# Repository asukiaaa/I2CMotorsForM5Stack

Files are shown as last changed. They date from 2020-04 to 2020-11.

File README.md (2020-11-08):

# I2cMotorsForM5Stack

A motor driver with using atmega328p for M5Stack.

# TODO

- Replace D3 to small current and high voltage one

# Components

- [TB6612FNG](http://akizukidenshi.com/catalog/g/gI-11317/)
- [Diode](https://akizukidenshi.com/catalog/g/gI-02073/)
- [Terminal block](https://akizukidenshi.com/catalog/g/gP-08370/)
- Gear motor 6v200rpm

# License

MIT

# References

- [SparkFun Motor Driver - Dual TB6612FNG (1A)](https://www.sparkfun.com/products/14451)
- [CavityForM5Stack](https://github.com/asukiaaa/CavityForM5Stack)
- [Arduino Pro Mini schematic (PDF)](https://www.arduino.cc/en/uploads/Main/Arduino-Pro-Mini-schematic.pdf)

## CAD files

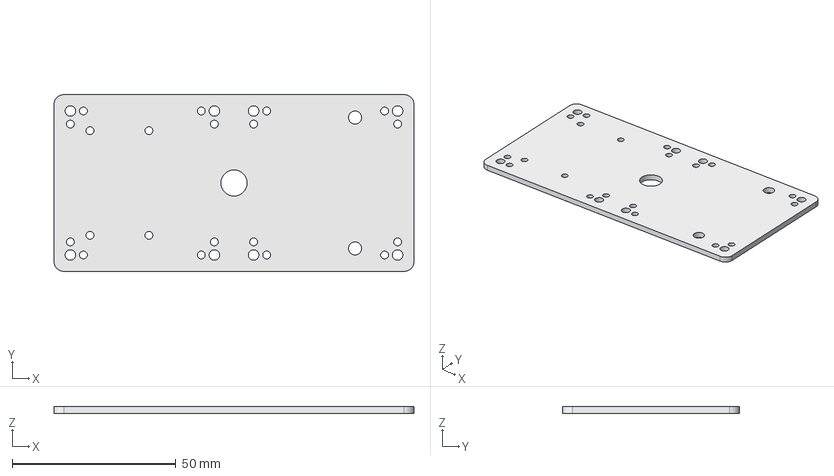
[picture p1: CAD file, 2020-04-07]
plate/plate.FCStd
110.0 x 54.0 x 2.00 mm

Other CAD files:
plate/plate.dxf

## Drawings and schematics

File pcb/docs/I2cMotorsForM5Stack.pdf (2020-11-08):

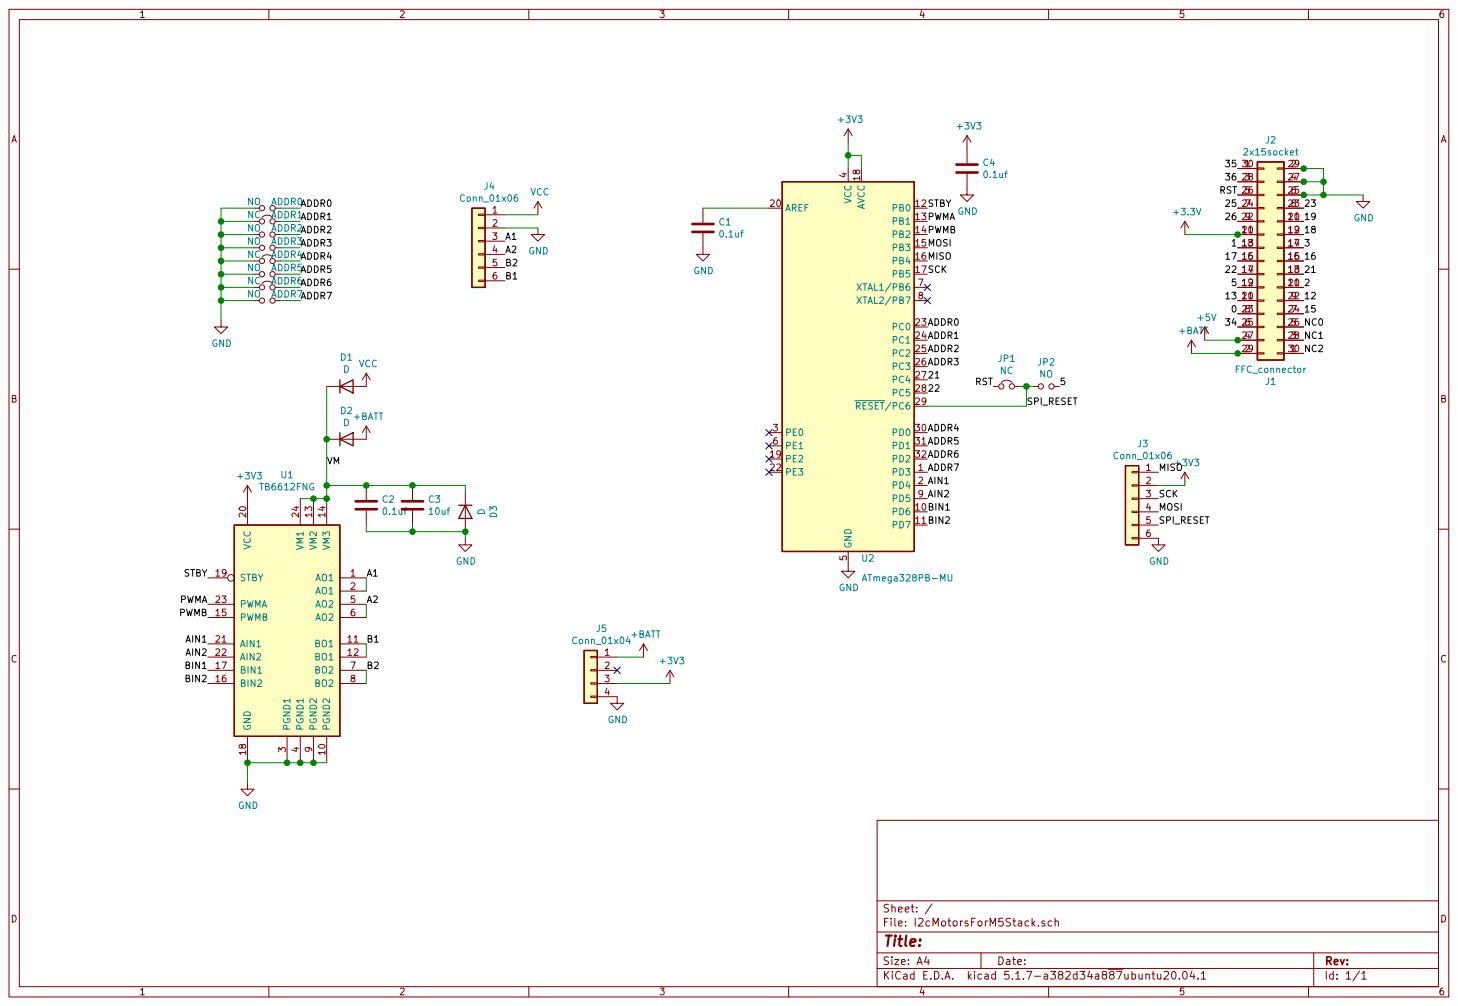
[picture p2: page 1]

Id: 1/1 Title: File: I2cMotorsForM5Stack.sch Sheet: /

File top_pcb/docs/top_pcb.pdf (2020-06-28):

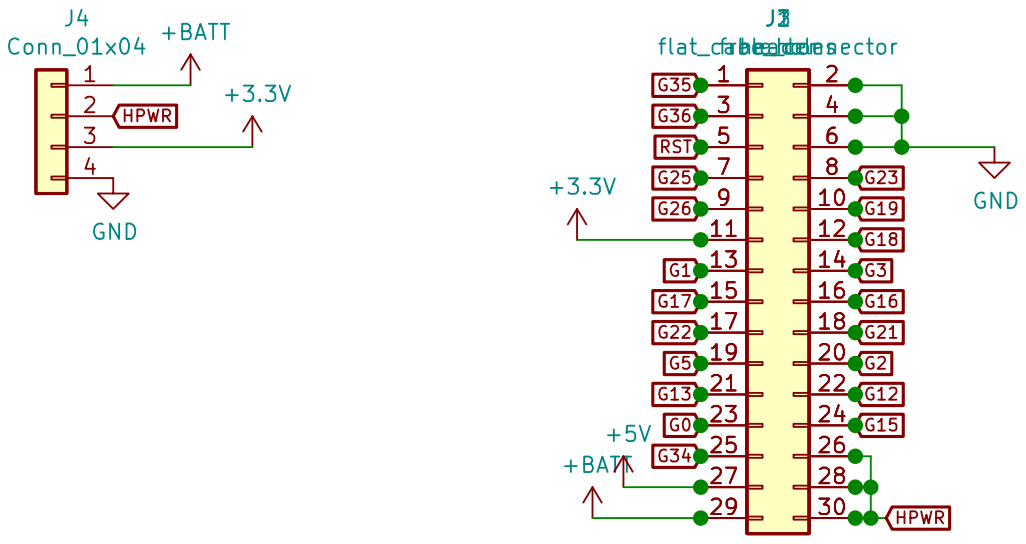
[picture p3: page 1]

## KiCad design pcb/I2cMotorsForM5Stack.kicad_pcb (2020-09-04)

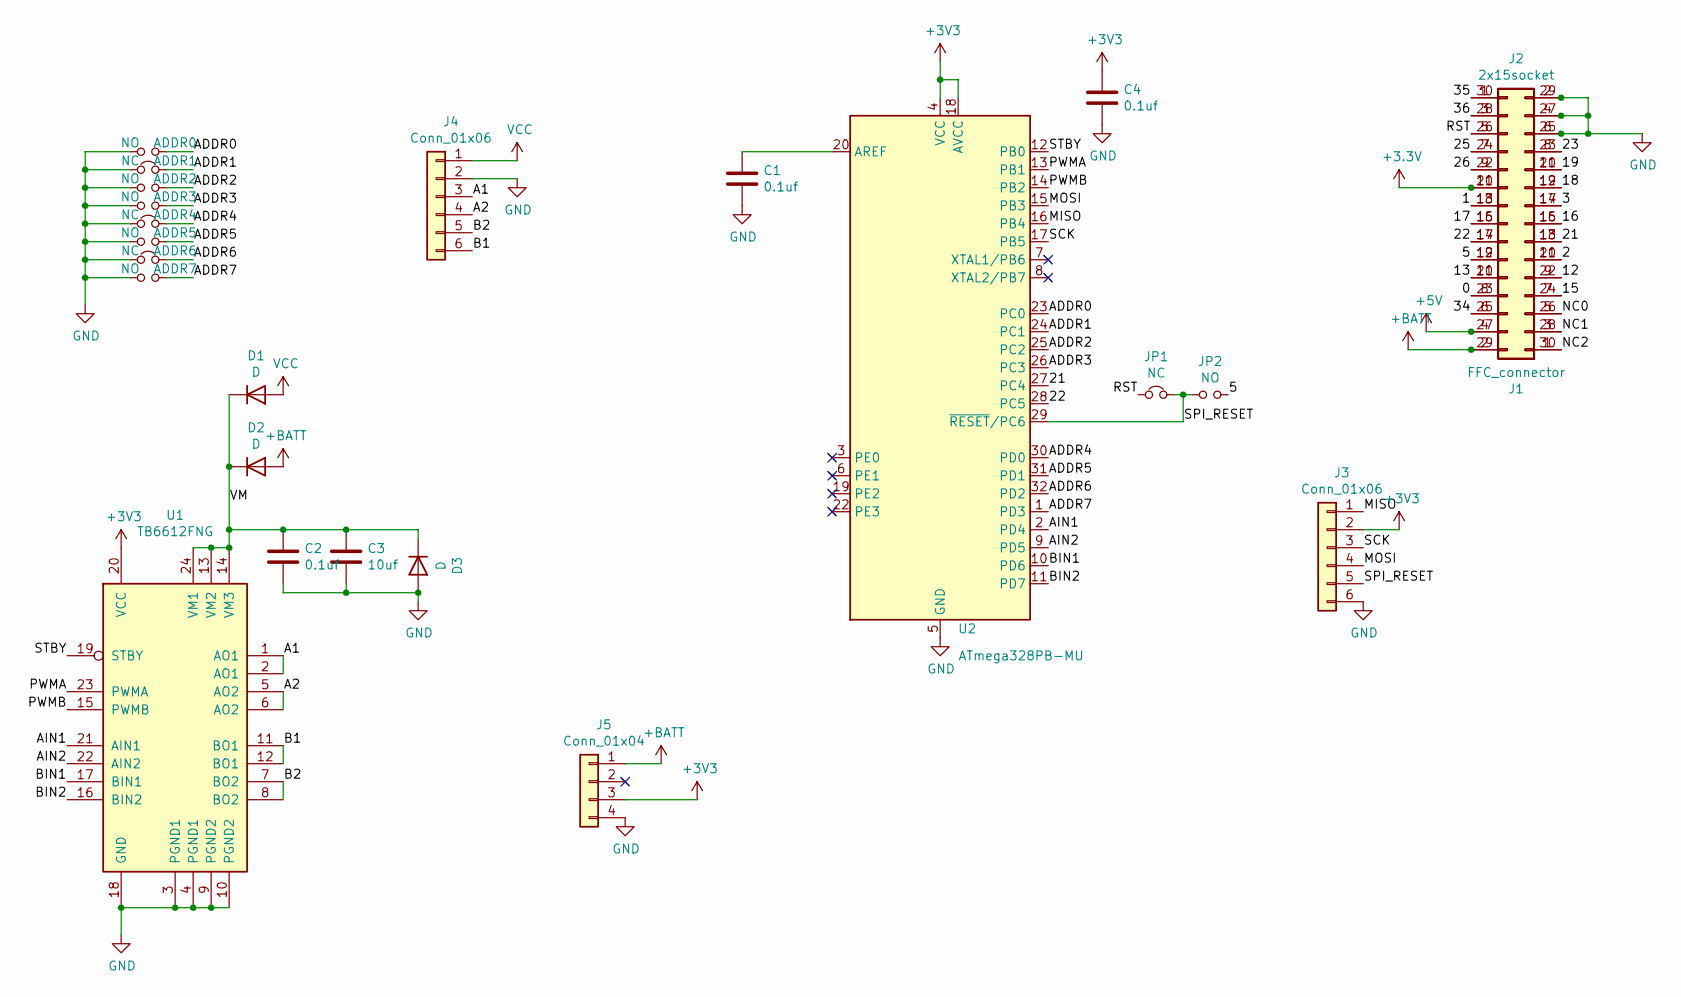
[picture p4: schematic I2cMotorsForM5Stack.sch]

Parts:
ADDR0, ADDR2, ADDR3, ADDR5, ADDR7: NO; SolderJumper-2_P1.3mm_Open_RoundedPad1.0x1.5mm
ADDR1, ADDR4, ADDR6: NC; SolderJumper-2_P1.3mm_Bridged_RoundedPad1.0x1.5mm
C1, C2, C4: 0.1uf; C_0603_1608Metric
C3: 10uf; C_0805_2012Metric
D1, D2, D3: D; D_SOD-123F
J1: FFC_connector; Hirose_FH12-30S-0.5SH_1x30-1MP_P0.50mm_Horizontal
J2: 2x15socket; PinSocket_2x15_P2.54mm_Vertical_SMD_just_for_M5Stack_bottom
J3: Conn_01x06; 2x03_P2.54mm_Pads
J4: Conn_01x06; TerminalBlock_bornier-6_P5.08mm
J5: Conn_01x04; NS-Tech_Grove_1x04_P2mm_Vertical
JP1: NC; SolderJumper-2_P1.3mm_Bridged_RoundedPad1.0x1.5mm
JP2: NO; SolderJumper-2_P1.3mm_Open_RoundedPad1.0x1.5mm
U1: TB6612FNG; SSOP-24_5.3x8.2mm_P0.65mm
U2: ATmega328PB-MU; QFN-32-1EP_5x5mm_P0.5mm_EP3.1x3.1mm

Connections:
+5V: J1.4, J2.27
+BATT: D2.2 (A), J1.2, J2.29, J5.1
/0: J1.8, J2.23
/1: J1.18, J2.13
/2: J1.11, J2.20
/3: J1.17, J2.14
/5: J1.12, J2.19, JP2.2
/12: J1.9, J2.22
/13: J1.10, J2.21
/15: J1.7, J2.24
/16: J1.15, J2.16
/17: J1.16, J2.15
/18: J1.19, J2.12
/19: J1.21, J2.10
/21: J1.13, J2.18, U2.27 (PC4)
/22: J1.14, J2.17, U2.28 (PC5)
/23: J1.23, J2.8
/25: J1.24, J2.7
/26: J1.22, J2.9
/34: J1.6, J2.25
/35: J1.30, J2.1
/36: J1.28, J2.3
/A1: J4.3, U1.1 (AO1), U1.2 (AO1)
/A2: J4.4, U1.5 (AO2), U1.6 (AO2)
/ADDR0: ADDR0.2, U2.23 (PC0)
/ADDR1: ADDR1.2, U2.24 (PC1)
/ADDR2: ADDR2.2, U2.25 (PC2)
/ADDR3: ADDR3.2, U2.26 (PC3)
/ADDR4: ADDR4.2, U2.30 (PD0)
/ADDR5: ADDR5.2, U2.31 (PD1)
/ADDR6: ADDR6.2, U2.32 (PD2)
/ADDR7: ADDR7.2, U2.1 (PD3)
/AIN1: U1.21 (AIN1), U2.2 (PD4)
/AIN2: U1.22 (AIN2), U2.9 (PD5)
/B1: J4.6, U1.11 (BO1), U1.12 (BO1)
/B2: J4.5, U1.7 (BO2), U1.8 (BO2)
/BIN1: U1.17 (BIN1), U2.10 (PD6)
/BIN2: U1.16 (BIN2), U2.11 (PD7)
/MISO: J3.1, U2.16 (PB4)
/MOSI: J3.4, U2.15 (PB3)
/NC0: J1.5, J2.26
/NC1: J1.3, J2.28
/NC2: J1.1, J2.30
/PWMA: U1.23 (PWMA), U2.13 (PB1)
/PWMB: U1.15 (PWMB), U2.14 (PB2)
/RST: J1.26, J2.5, JP1.1
/SCK: J3.3, U2.17 (PB5)
/SPI_RESET: J3.5, JP1.2, JP2.1, U2.29 (~RESET~/PC6)
/STBY: U1.19 (STBY), U2.12 (PB0)
/VM: C2.1, C3.1, D1.1 (K), D2.1 (K), D3.1 (K), U1.13 (VM2), U1.14 (VM3), U1.24 (VM1)
GND: ADDR0.1, ADDR1.1, ADDR2.1, ADDR3.1, ADDR4.1, ADDR5.1, ADDR6.1, ADDR7.1, C1.2, C2.2, C3.2, C4.2, D3.2 (A), J1.25, J1.27, J1.29, J2.2, J2.4, J2.6, J3.6, J4.2, J5.4, U1.3 (PGND1), U1.4 (PGND1), U1.9 (PGND2), U1.10 (PGND2), U1.18 (GND), U2.5 (GND), U2.21 (GND), U2.33 (GND)
unnamed: C1.1, U2.20 (AREF)
VCC: D1.2 (A), J4.1

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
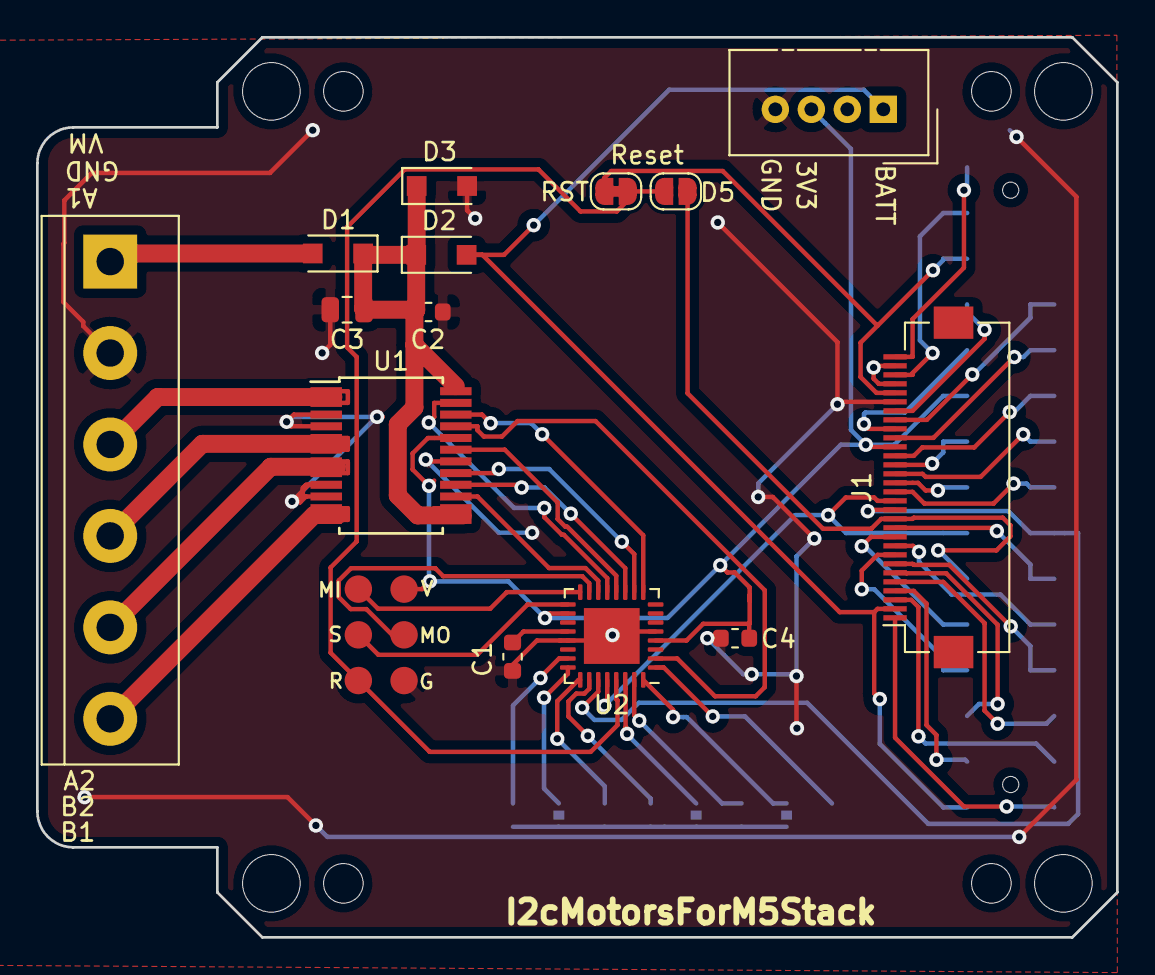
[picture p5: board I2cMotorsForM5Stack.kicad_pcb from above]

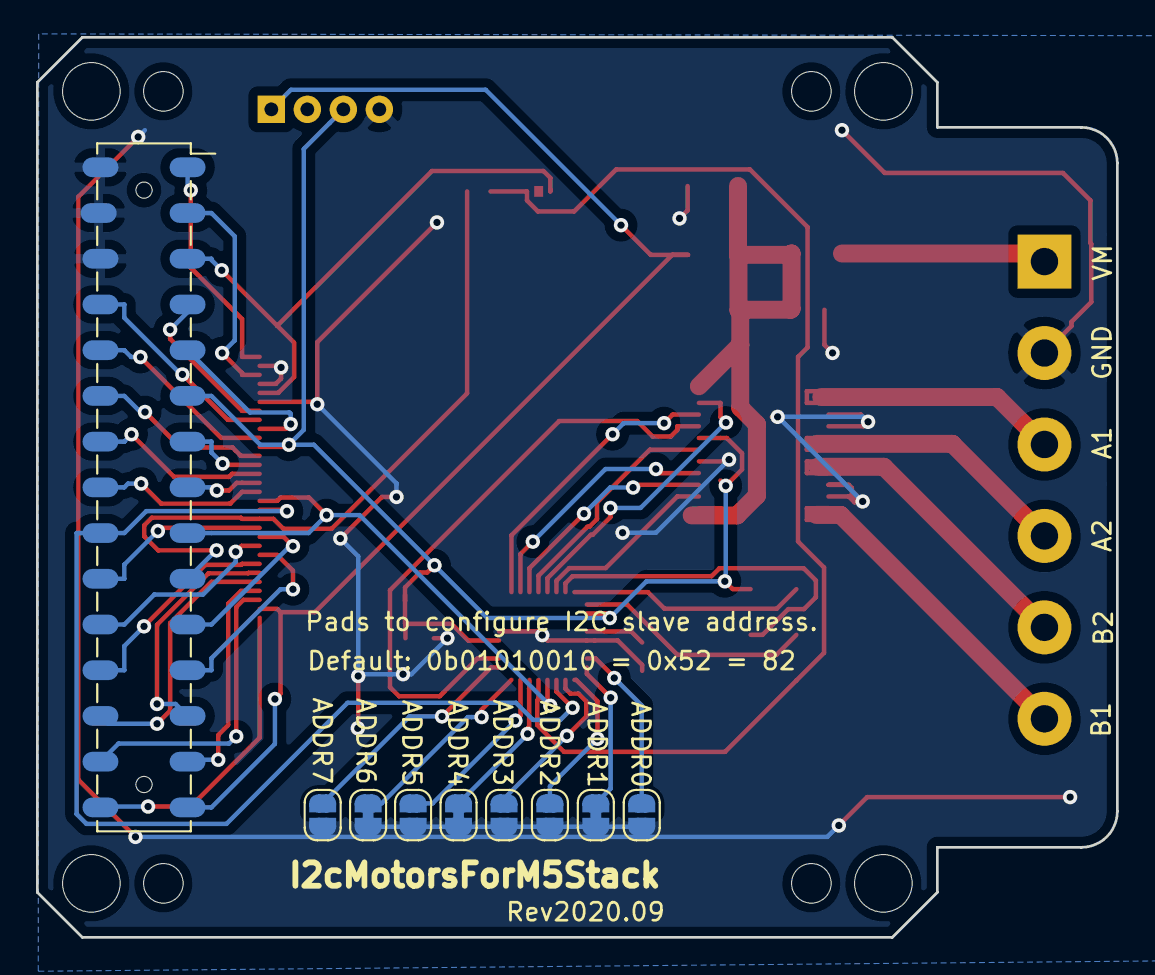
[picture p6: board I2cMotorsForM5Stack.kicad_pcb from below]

Board: 2 copper layers, 60.0 x 50.0 mm, 32 parts (9 on the bottom side), 54 nets.

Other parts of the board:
REF1, REF4, REF6, REF9: MountingHole_3.2mm_M3
REF2, REF3, REF7, REF8: MountingHole_2.2mm_M2

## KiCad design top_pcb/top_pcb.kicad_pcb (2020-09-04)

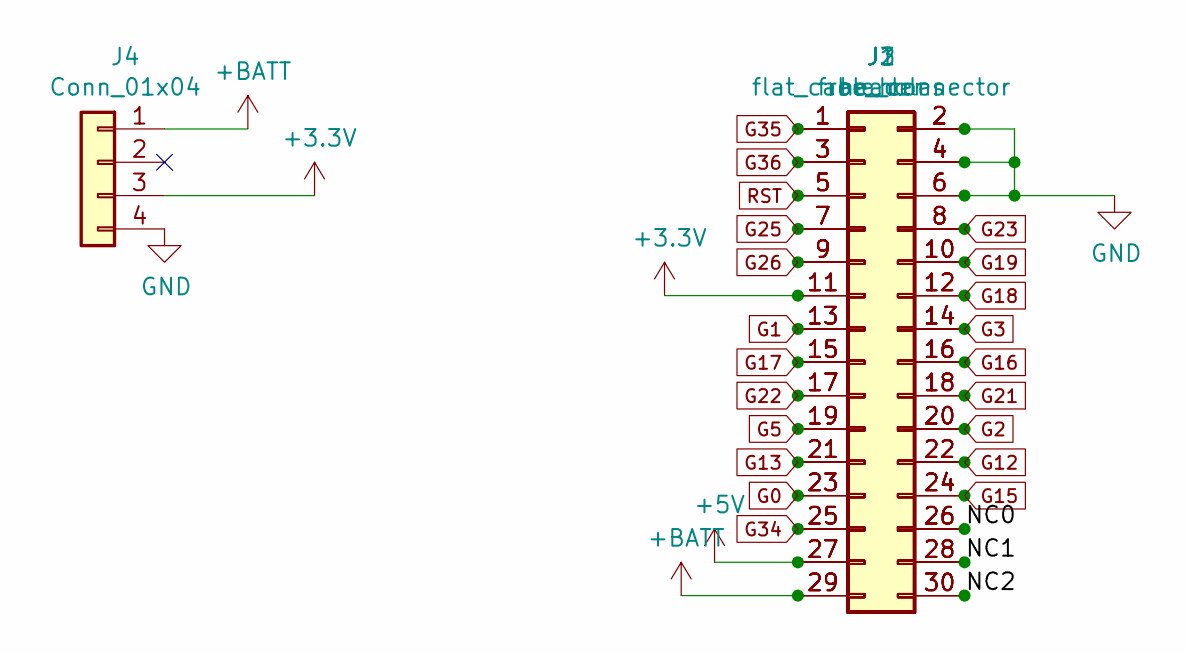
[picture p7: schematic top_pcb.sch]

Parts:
J1: flat_cable_connector; Hirose_FH12-30S-0.5SH_1x30-1MP_P0.50mm_Horizontal
J2: header; PinHeader_2x15_P2.54mm_Vertical_SMD_for_M5Stack
J3: free_holes; PinHeader_1x30_P1.27mm_Vertical_without_silks
J4: Conn_01x04; NS-Tech_Grove_1x04_P2mm_Vertical

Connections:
+3V3: J1.11, J2.11, J3.11, J4.3
+5V: J1.27, J2.27, J3.27
+BATT: J1.29, J2.29, J3.29, J4.1
/NC0: J1.26, J2.26, J3.26
/NC1: J1.28, J2.28, J3.28
/NC2: J1.30, J2.30, J3.30
G0: J1.23, J2.23, J3.23
G1: J1.13, J2.13, J3.13
G2: J1.20, J2.20, J3.20
G3: J1.14, J2.14, J3.14
G5: J1.19, J2.19, J3.19
G12: J1.22, J2.22, J3.22
G13: J1.21, J2.21, J3.21
G15: J1.24, J2.24, J3.24
G16: J1.16, J2.16, J3.16
G17: J1.15, J2.15, J3.15
G18: J1.12, J2.12, J3.12
G19: J1.10, J2.10, J3.10
G21: J1.18, J2.18, J3.18
G22: J1.17, J2.17, J3.17
G23: J1.8, J2.8, J3.8
G25: J1.7, J2.7, J3.7
G26: J1.9, J2.9, J3.9
G34: J1.25, J2.25, J3.25
G35: J1.1, J2.1, J3.1
G36: J1.3, J2.3, J3.3
GND: J1.2, J1.4, J1.6, J2.2, J2.4, J2.6, J3.2, J3.4, J3.6, J4.4
RST: J1.5, J2.5, J3.5

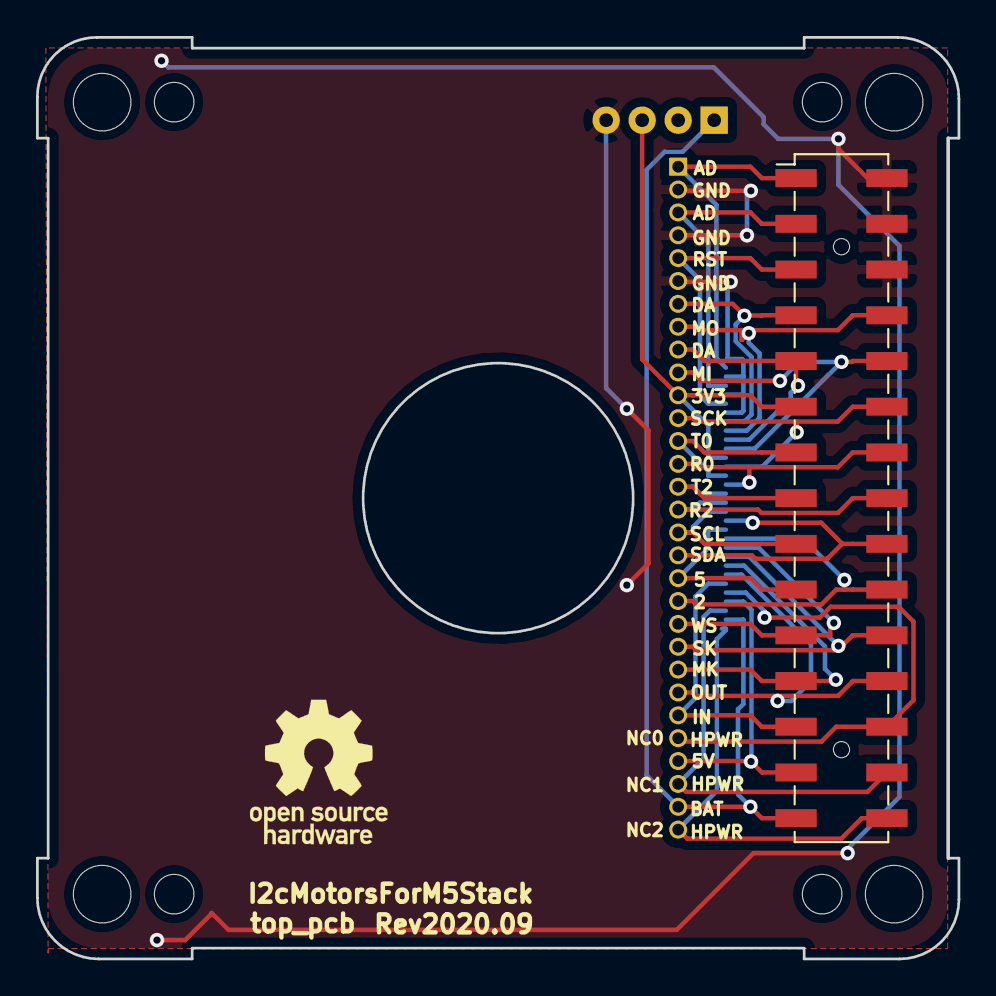
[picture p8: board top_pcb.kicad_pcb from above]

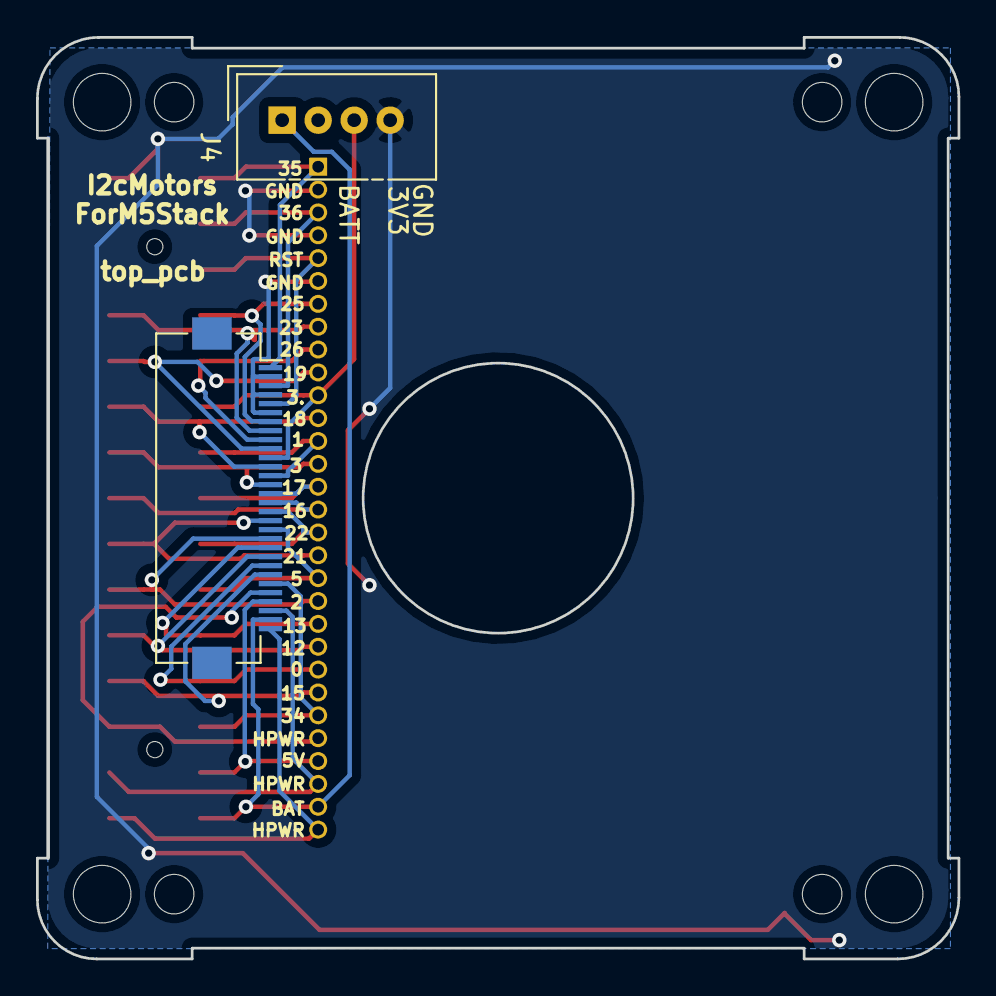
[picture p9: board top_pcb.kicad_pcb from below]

Board: 2 copper layers, 51.2 x 51.2 mm, 17 parts (2 on the bottom side), 28 nets.

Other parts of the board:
OSHWREF2: OSHW-Logo_7.5x8mm_SilkScreen
REF1, REF4, REF6, REF9: MountingHole_3.2mm_M3
REF2, REF3, REF7, REF8: MountingHole_2.2mm_M2
corner1, corner4: corner_edge1
corner2, corner3: corner_edge2

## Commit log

2020-02-20 Create pcb folder
    [I2CMotorsForM5Stack-B_Cu.gbl, I2CMotorsForM5Stack-B_Cu.gbr, I2CMotorsForM5Stack-B_Mask.gbr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]
2020-02-20 Add plate that uses motor holder
    [plate.FCStd, plate.dxf]
2020-02-22 Update design of plate to use small moter with 2 plates
    [plate.FCStd, plate.dxf]
2020-02-23 Update position of holes for a caster
    [plate.FCStd, plate.dxf]
2020-02-23 Add holes to horizontal mount for M5Stack
    [plate.FCStd, plate.dxf]
2020-03-02 Update outer size of plate
    [plate.FCStd, plate.dxf]
2020-03-09 Put terminal mount out side of m5stack zone
    [I2CMotorsForM5Stack.kicad_pcb, I2CMotorsForM5Stack.sch]
2020-03-10 Remove redundant files
    [I2CMotorsForM5Stack-B_Cu.gbl, I2CMotorsForM5Stack-B_Cu.gbr, I2CMotorsForM5Stack-B_Mask.gbr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]
2020-03-10 Add gerber_to_order to gitignore
2020-03-10 Use rounded corner
    [I2CMotorsForM5Stack.kicad_pcb]
2020-03-30 Add diode to connect VM and GND
    [I2CMotorsForM5Stack.kicad_pcb, I2CMotorsForM5Stack.sch]
2020-03-30 Assign thick line to motor power
    [I2CMotorsForM5Stack.kicad_pcb, I2CMotorsForM5Stack.sch]
2020-03-30 Add connectors and address pads
    [I2CMotorsForM5Stack.kicad_pcb, I2CMotorsForM5Stack.sch]
2020-04-07 Update plate to use hole castor
    [plate.FCStd, plate.dxf]
2020-05-02 Change start number for address pad
    [I2CMotorsForM5Stack.kicad_pcb, I2CMotorsForM5Stack.sch]
2020-05-02 Correct accidentaly connected line
    [I2CMotorsForM5Stack.kicad_pcb]
2020-05-02 Add connector to support power lines
    [I2CMotorsForM5Stack.kicad_pcb, I2CMotorsForM5Stack.sch]
2020-05-02 Update revision to 2020.05
    [I2CMotorsForM5Stack.kicad_pcb]
2020-05-02 Add top_pcb
    [top_pcb.kicad_pcb, top_pcb.sch]
2020-05-02 Add explanation about pads to configure address
    [I2cMotorsForM5Stack.kicad_pcb]
2020-06-28 Update something
    [I2cMotorsForM5Stack.kicad_pcb, I2cMotorsForM5Stack.sch]
2020-06-28 Ignore gerber_to_order for top_pcb
2020-06-28 Remove accidentaly connected gnd line to battery pad
    [top_pcb.kicad_pcb]
2020-06-28 Update rpm for gear motor
2020-09-04 Separate HPWR to NC0-2 for Core2
    [I2cMotorsForM5Stack.kicad_pcb, I2cMotorsForM5Stack.sch, top_pcb.kicad_pcb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]
2020-11-08 Update pdf of schematic
    [I2cMotorsForM5Stack.sch]
